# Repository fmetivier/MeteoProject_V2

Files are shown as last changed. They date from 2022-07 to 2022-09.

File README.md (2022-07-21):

# MeteoLog V2: an Autonomous NON connected Meteorologic Station using Arduino that records PRECIPITATION TIME

* [Introduction](##introduction)
* [Station](##station)
* [Arduino scripts](##arduino-scripts)
* [Python and SQL](##python-and-sql)

## Introduction 

The project aims at developping a lowcost meteorologic station with the following properties
* The station's main purpose is to measure rainfall but temperature and humidity are also included,
* it has to be solar powered,
* it has to store the data on an SD card
* it has to capture the time the pluviometer auget tilts and NOT the number of tilts during a given time period (what most if not all other pluviometers do).

If the last point is unimportant for you I suggest you use the Meteolog Project as it consumes less power.

Included are the references needed to build the station, the electronic and the codes needed to have it run.

## The station 

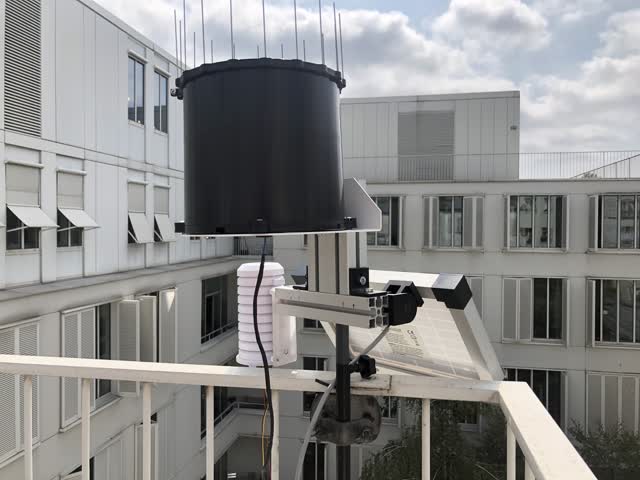
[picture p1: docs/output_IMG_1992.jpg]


### Structure & parts

* Watchdog auger pluviometer that sends a small voltage when the auger tilts. The one I bought is uselessly expensive (400€) because  it includes an electronic logger that I do not wish to use here because (1) its time resolution is too limited, (2) it is not solar powered, (3) it has to be used with some silly expensive (100€) windows program to retrieve the data.
You can get the equivalent without the logger for ~ 100€ (Yeap..., look at Rainwise for exemple)
* Temperature and humidity sensor DHT11 (3.5€). A DHT22 (10.2€) would be better as it is more precise (0.5° and 2% compared to 2° and 5% for the DHT11).
* 10W SOL10P Solar panel (36.5€)
* 12V, 5.4Ah Lead battery (29€)
* DFRobot Sunflower 3.3/5/9/12 DFR0535 to handle the solar panel and the battery(32€),
* Housing for DHT11 by TFA Dostman (18€)
* Box for the electronic
* Rod and Norcan to hold everything

### Electronic

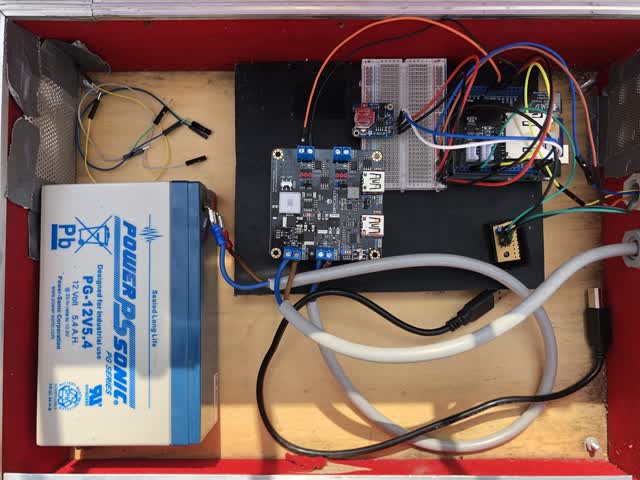
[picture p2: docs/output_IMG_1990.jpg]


* Arduino Uno Rev 3
* RTC module to keep track of time
* The auger pluviometer is connected to the digital port 2 that enables interruptions to be raised. I add a capacitor to prevent false counts.
* SDcard module to store the data
* Solar charger connected to Lead battery and to the Uno.

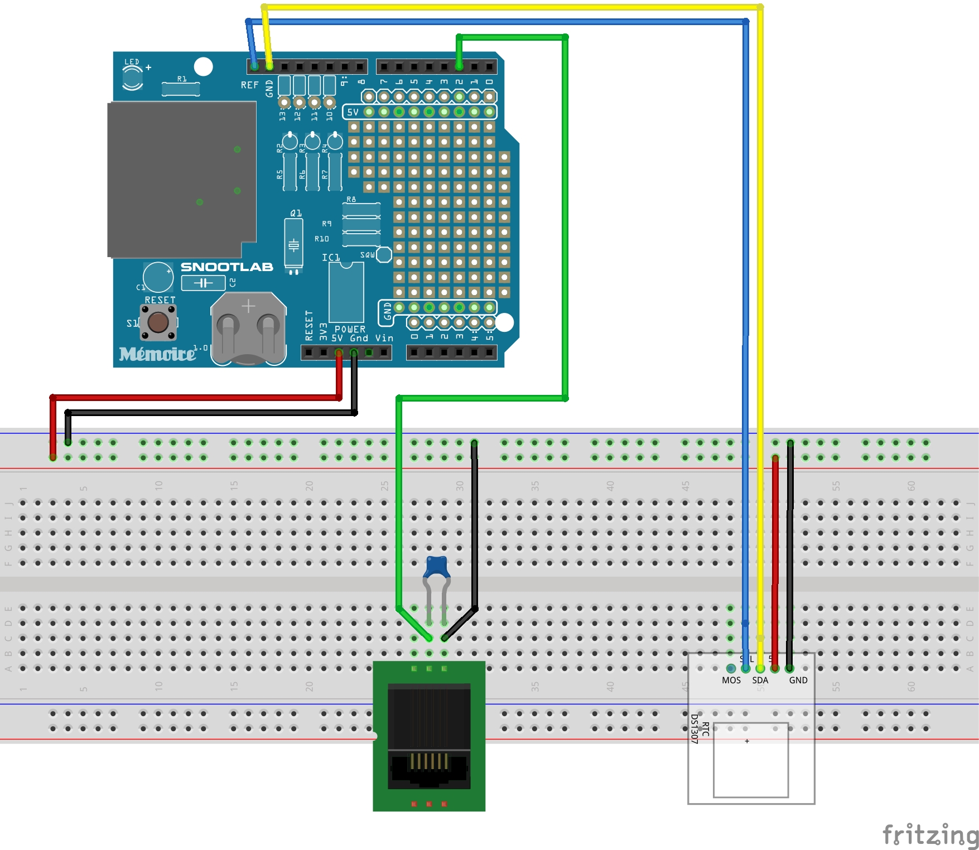
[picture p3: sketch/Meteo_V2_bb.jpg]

Note that solar panel and lead battery connection to the DFR sunflower module and its connection to Vin/GND are not depicted here.

## Arduino scripts 

### UnoMeteoLoggerNoSleep

This arduino is constantly awaken and reacts if an interrupt is raised by an auger tilt. In that case it records time. The arduino also stores Temparature and humidity every five minutes.

### RTCInitialize

this script set the time of the RTC clock. It has to be uploaded first, then you can upload the UnoMeteoLoggerNoSleep script.
Clock initialization has to be performed independantly. This prevents reinitialisation of the RTC each time the arduino restarts the UnoMeteoLoggerNoSleep script.

## Python and SQL 

I use a Mariadb database to store the data once retrieved from the SDcard. I call the base weatherDB.
The table has three tables

a station table that records the information concerning the stations, a TH table where temperature and humidity is stored, and a P table where the time of tilt of the rainfall gage is recorded.

The structure tables is given below

### Stations
| Field| Type| description|
|---|---|---|
|stcode| varchar | station code|
|name| varchar | name of the station|
|longitude| float| geodetic|
|latitude|float | geodetic|
|elevation|float||
|comment|varchar| any comment|

### TH

| Field| Type| description|
|---|---|---|
|mdate| date| date of measurement|
|mtime| time| time of measurement|
|T| float| temperature|
|H| float| Humidity|
|stcode| varchar| station code|
|dcode| int| record code|

### P   
| Field| Type| description|
|---|---|---|
|pcode| int| record code|
|mdate| date| date of m  easurement|
|mtime| time| time of measurement|
|N| int| count normally 1|
|stcode| varchar| station code|

The stations table records the Station informations so it becomes possible to store the data from as many stations as we wish (once they're built !)

A sample of the database is given in data. To install the database you need to have a running version of MariaDB or Mysql server.

One way recreate the database is to open a terminal in the data folder and enter the following command
```mysql
mysql -u<your login> -p<your pass> < weatherDB.sql
```

 Once installed
enter your  your SQL identifiers  in the mylogin.txt file.
You can then run the demo scripts from Meteo.py

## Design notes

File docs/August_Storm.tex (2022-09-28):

\documentclass[12pt,a4paper]{article}
\usepackage[utf8]{inputenc}
\usepackage[francais]{babel}
\usepackage[T1]{fontenc}
\usepackage{amsmath}
\usepackage{amsfonts}
\usepackage{amssymb}
\usepackage{graphicx}
\usepackage[left=2cm,right=2cm,top=2cm,bottom=2cm]{geometry}
\begin{document}
\begin{abstract}
Nous analysons les précipitations du 16 août 2022 à Paris quand un orage de grande ampleur s'est abattu sur la ville. Nous utilisons les données d'un pluviomètre à auget basculeur modifié. La modification consiste à enregistrer les instants de bascule de l'auget et non  à comptabiliser le nombre de bascule durant une durée (la plus fréquente étant de 1 heure). Dans le cas d'un orage extrêmement intense mais de courte durée (moins d'une heure et demi) nous montrons l'intérêt de ce genre de modification peu couteuse.
\end{abstract}

Il est tombé $31.5$ mm de pluie entre 16:46:45 et 18:08:21 UTC sur le toit de la terrasse du 5ème étage le 16 Août 2022.
soit $1.36$ heure ou encore 1 heure 21 minutes et 36 secondes. La précipitation horaire moyenne est donc de  23.16 mm/h sur l'IPG. 
cet orage à été enregistré au travers de 126 basculement de l'auget.
Les deux stations voisine dont les données sont en accès libre, celle du LATMOS et celle situé dans le 6ème à saint Germain donne des valeurs proches: $30.8$mm entre 16h et 19h pour la station de Saint Germain des Prés et $35$mm entre 16h et 19h pour la station du LATMOS.

Si on considère un histogramme de pluie tel qu'il est fournit par n'importe quelle station classique avec un pas de temps horaire

Si on améliore progressivement la précision tout en gardant un pas constant on tombe sur le problème des valeurs nulles de précipitation. 

la meilleure solution avec un auget consiste à enregistrer les temps de bascule. l'intensité est alors donnée par
\begin{equation}
I = H/dt 
\end{equation}
ou $H$ correspond à la hauteur de précipitation d'un auget rempli et $dt$ l'intervalle entre les deux bascules.Dans notre cas $H=0.25$mm. 

La limite est ici imposée en théorie par la valeur de H et en pratique par la précision de l'horloge qui dans la plupart des cas est (pour des raisons de coût) de 1 seconde. La valeur maximale $I_{max}$ est donc donnée par
\begin{equation}
I_max = H/1 = H
\end{equation}
soit $I_{max} = 2.5\cdot 10^{-4}$m/s dans notre cas ou encore dans une unité que tout le monde comprend $900$ mm/h

Dans le cas du 16 Août l'orage était réellement exceptionnel la période la plus courte entre deux bascules de l'auget est de 4 secondes soit une intensité de $225$mm/h ou $6.25\cdot 1{-5}$m/s 

\begin{figure}[hbtp]
\centering

\caption{}
\end{figure}

\end{document}

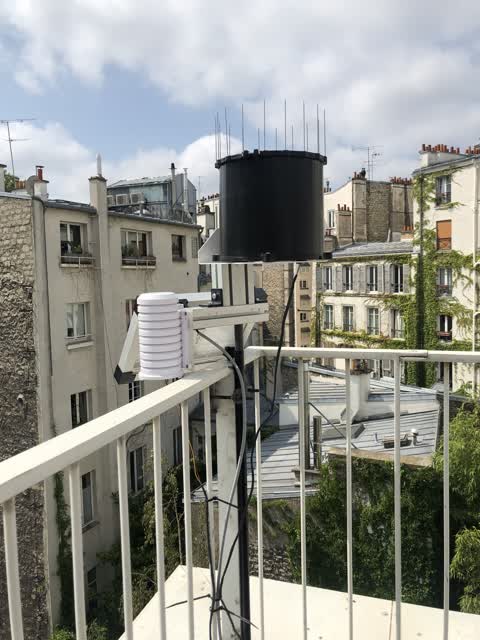
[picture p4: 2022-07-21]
docs/output_IMG_1991.jpg

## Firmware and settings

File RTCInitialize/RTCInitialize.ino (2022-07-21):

// Date and time functions using a DS1307 RTC connected
// via I2C and Wirelib
// <jc@wippler.nl> http://opensource.org/licenses/mit-license.php
#include <Wire.h>
#include <RTClib.h>
#define ADRESSE_I2C_RTC 0x68 // RTC card address

RTC_DS1307 RTC;
void setup ()
{
Serial.begin(9600); // Initialisation de la liaison série
Wire.begin();
Wire.beginTransmission(ADRESSE_I2C_RTC);
RTC.begin();
// Cette ligne permet de définir une heure de départ pour le module RTC
//(Année, mois, jour, //heure, minute, seconde)
// Elle peut être mise en commentaire une fois le module mis Ã jour.

  RTC.adjust(DateTime(F(__DATE__), F(__TIME__)));
  Serial.println("Horloge mise à jour");
Wire.endTransmission();


}
void loop ()
{
  Wire.beginTransmission(ADRESSE_I2C_RTC);
  DateTime now = RTC.now();
  Wire.endTransmission();
Serial.print(now.day(), DEC);
Serial.print('/');
Serial.print(now.month(), DEC);
Serial.print('/');
Serial.print(now.year(), DEC);
Serial.println(' ');
Serial.print(now.hour(), DEC);
Serial.print(':');
Serial.print(now.minute(), DEC);
Serial.print(':');
Serial.print(now.second(), DEC);
Serial.println();
delay(3000);

}

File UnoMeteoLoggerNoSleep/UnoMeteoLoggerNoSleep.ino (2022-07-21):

//SD Card lib
#include <SPI.h>
#include <SD.h>
const int chipSelect = 4; // SD card on Nano

//RTC lib
#include <Wire.h>
#include <RTClib.h>
#define ADRESSE_I2C_RTC 0x68 // RTC card address
RTC_DS1307 rtc;

// DHT sensor lib
#include <DHT_U.h>
#include <DHT.h>
#define DHT_TYPE DHT11
#define DHT_PIN 7
DHT dht(DHT_PIN,DHT_TYPE);


const byte pluvio = 2;  // pullup for pluviometer on D2
volatile int pcount = 0;
long t0 = 0;



void setup()
{
  Serial.begin(9600); // pour affichage dans le moniteur série
  
  pinMode(pluvio, INPUT_PULLUP);
 
  attachInterrupt(digitalPinToInterrupt(pluvio), pCount, FALLING);

  while (!Serial) {
   delay(100) ; // wait for serial port to connect. Needed for native USB port only
  }

  Wire.begin();
  Wire.beginTransmission(ADRESSE_I2C_RTC);
  while (!rtc.begin()){
      Serial.println("Attente module HTR");
      delay(1000);
  }
  Wire.endTransmission();

  dht.begin(); 

  Serial.print("Initializing SD card...");

  // see if the card is present and can be initialized:
  if (!SD.begin(chipSelect)) {
    Serial.println("Card failed, or not present");
    // don't do anything more:
    //while (1);
  }
  else {
    Serial.println("card initialized.");
  }
}

void loop()
{
  Wire.beginTransmission(ADRESSE_I2C_RTC);
  DateTime now = rtc.now();
  Wire.endTransmission();

  char sdate[12];
  sprintf(sdate,"%04d:%02d:%02d",now.year(),now.month(),now.day());
  char stime[10];
  sprintf(stime,"%02d:%02d:%02d",now.hour(),now.minute(),now.second());
 
  // input voltage
  //int sensorValue = analogRead(A0);


 if (pcount > 0){
 
  String dataString =  "p,";
  dataString +=  String(sdate) + "," + String(stime) + "," +  String(pcount) + "\n";
  Serial.print(dataString);

  writeData(dataString);
  pcount=0;
 }
 if (abs(now.unixtime()-t0) >= 300){

 
  float t = dht.readTemperature();
  float h = dht.readHumidity();
  
    
    String dataString = "w," + String(sdate) + "," + String(stime) + "," + String(t) + " , " + String(h) + "\n";
    
   Serial.print(dataString);
    writeData(dataString);
    Serial.println(now.unixtime()-t0);
    t0 = now.unixtime();
    Serial.println(t0);
 
    
 }
  
}



void writeData(String dataString)
{
  if (SD.begin(chipSelect)){
  
     File dataFile = SD.open("METEOLOG.TXT", FILE_WRITE);
  
     // if the file is available, write to it:
     if (dataFile) {
      dataFile.print(dataString);
      dataFile.close();
     }
     // if the file isn't open, pop up an error:
     else {
       Serial.println("error opening METEOLOG.TXT");
     }
   }
   else{
    Serial.println("No card available. Loosing data");
   }
}


void pCount()
{

  pcount += 1;
  
}
